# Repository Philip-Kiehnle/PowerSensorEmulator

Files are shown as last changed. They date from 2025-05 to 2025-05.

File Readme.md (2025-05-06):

# Motivation
To measure household electricity consumption in a typical photovoltaic or battery system in Germany, an additional power sensor is installed alongside the grid operator's electricity meter. This additional power sensor can be accessed directly by the Hybrid- or Batteryinverter, because a compatible model is installed by the PV installer or electrician.  
Many models use a Modbus RTU (RS-485) interface with a typical update rate of 1 to 4 Hz.

System overview:

System Overview

This setup has some advantages and disadvantages.  
Disadvantages:
- Device cost of 100–300 € for the extra power sensor
- Installation cost, electrician needed
- Space required in the cabinet
- Power offset between grid operator's electricity meter and extra power sensor, 3–10 Watt
- Power consumption of the device, 0.4–2 Watt
- Minimal voltage/power loss in the main power cable, e.g. due to:
  - Longer cables have to be installed for the measurement setup.
  - A power sensor with an internal current measuring path is installed, as in the [Kaco Hy-switch](https://github.com/Philip-Kiehnle/kaco_blueplanet_hybrid10/tree/main/power_sensor).
  - Clamp current sensors have some loss in their cores.

Advantages:
+ Decent update rate of the power measurement enables fast settling time of the control loop
+ High reliability of the setup because of compatible power meter and inverter
 (Both arguments may be neglected in the future, see section [Impact on system performance](#impact-on-system-performance))

-> Let's take a different approach and use the "already there" optical infrared interface from the grid operator's energy/power meter and develop a protocol conversion adapter that behaves like a compatible power sensor.

# STM32 Microcontroller used as an Emulator for Chint Smart Power Sensor

The first prototype uses an optical read head, a microcontroller, and an RS-485 transceiver.

The optical read head is magnetically attached to the optical interface of the electricity meter. These readers are available online in several versions. Some include a WiFi module such as an ESP32, but for this project the bare UART output model is used. The read head converts the optical UART to an electrical UART signal. The UART signal is connected to the microcontroller, which decodes the Smart Message Language (SML) frames, sent by the electricity meter.  
Three elements are decoded:  

| OBIS code | Description | Variable name in software |
| --- | --- | --- |
| 16.7.0 | Sum active instantaneous power | power |
| 1.8.0 | Positive active energy total | energy_import |
| 2.8.0 | Negative active energy total | energy_export |

The STM32l432kc Nano devboard from ST Microelectronics was used. Its STM32L432KCU3 microcontroller runs at 32 MHz. The microcontroller implements a Modbus slave using the same registers as the original Chint power sensor. An RS-485 transceiver connects the microcontroller and the inverter (Huawei SUN2000-10KTL).

A breadboard was soldered to add connectors and the RS-485 transceiver.  
The prototype requires the following connections:
| Connector | Description |
| --- | --- |
| USB-Power | 5 V supply, e.g. from a 230 V power supply |
| Infrared Read Head | 4 pins for the infrared adapter: VCC, GND, TX, RX.<br>TX can be used in future software version to (re-)enter the meter key in case of a reset during a power outage. The manual [key input procedure](https://youtu.be/aqHauk3bNFA) can be avoided. |
| RS-485 | 2 pins for connection to the inverter |

The prototype uses the following LED states:  
Yellow LED toggles with every decoded SML message of the Smart Meter.  
Green LED toggles on activity on the RS-485 bus.  
Both LEDs toggle fast at 10 Hz when an error handler is called. A microcontroller reboot is triggered automatically after 60 seconds. 

The setup looks like this:

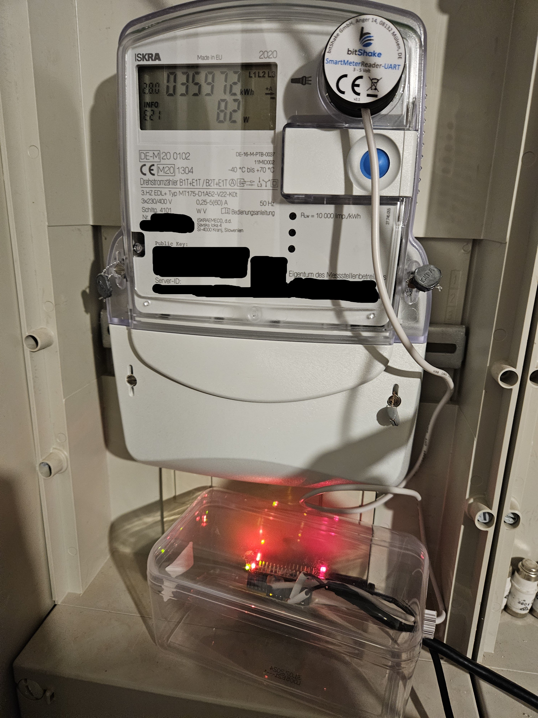
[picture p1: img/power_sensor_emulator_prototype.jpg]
Prototype installation


## Power Consumption
The device is powered from the 230 V grid using an USB power supply.  
The power consumption was measured using the ELV Energy Master power meter:  
5 V 500 mA power supply: 0.4-0.5 W  
Reference test: 5 V 2 A Samsung power supply: 0.4 W

## Cost
STM devboard 18 €  
IR Smart Meter Reader (bitshake UART) 24 €  
RS-485 IC 1 €  
-> 43 €  
-> In a redesigned solution, everything should fit in the infrared reader magnet head.  

## ToDo
Every ~3 month, the prototype needs a power reset, because the Huawei monitoring  shows an error.  
-> Log the communication frames during this situation.

The use of a Huawei battery is untested. If the inverter control loop does not expect the increased delay time of the power measurement, instabilities may occur. In this case, a dead-time compensation (DTC) such as a Smith predictor must be implemented in the power sensor emulator software.

# Chint Smart Power Sensor DTSU666-H

To find the register list of the original Chint Power Sensor, this repo was helpful:
https://github.com/lmatula/ha_chint_pm

## Power Consumption
Single phase connected, all current sensors connected. The power consumption was measured using the ELV Energy Master power meter:  
Display Backlight ON : 0.6 W / 0.6 VA  
Display Backlight OFF: 0.45 W / 0.45 VA

According to datasheet:
Voltage: < 1 W (per phase)  
Current: < 1 VA (per phase) < 20 mA (per phase)

According to Huawei online manual:  
Power consumption of voltage: ≤ 1.5 W / 6 VA  
Power consumption of current: Ib < 10 A : ≤ 0.2 VA   Ib ≥ 10 A :≤ 0.4 VA

### Findings
Data update rate of the Chint Power Sensor?  
-> Registers change with a rate of about 13.6 Hz.

Modbus read interval of the Huawei inverter?  
-> According to Modbus log between 3 and 4 Hz.

Is an exact voltage measurement necessary for the inverter to detect the correct installation of the Chint Power Sensor?  
-> Don't think so, because the original Chint sensor will be detected even if only one phase is connected.

# Data Comparison

Python Modbus register read, with a single phase connected to Chint Power Sensor:

| Key | Chint Power Sensor | STM32 Power Sensor Emulator |
|---|---|---|
| addr | 3 | 3 |
| baud | 11 | 11 |
| clre | 0 | 0 |
| day | 0 | 1 |
| dmpt | 0.0 | 0.0 |
| expep | 0.0 | 0.0 |
| freq | 50.0 | 50.0 |
| hour | 0 | 1 |
| ia | 0.003000000026077032 | 0.0 |
| ib | 0.008999999612569809 | 0.0 |
| ic | 0.00800000037997961 | 0.0 |
| impep | 0.0 | 0.0 |
| irat | 1 | 1 |
| meter_type | 1 | 1 |
| minutes | 17 | 1 |
| month | 0 | 4 |
| net | 0 | 0 |
| pa | 0.10000000149011612 | 0.0 |
| pb | 0.0 | 0.0 |
| pc | 0.0 | 0.0 |
| pfa | 1.0 | 1.0 |
| pfb | 1.0 | 1.0 |
| pfc | 1.0 | 1.0 |
| pft | 1.0 | 1.0 |
| protocol | 3 | 3 |
| pt | 0.10000000149011612 | 0.0 |
| q1eq | 0.0 | 0.0 |
| q2eq | 0.0 | 0.0 |
| q3eq | 0.0 | 0.0 |
| q4eq | 0.0 | 0.0 |
| qa | 0.10000000149011612 | 0.0 |
| qb | 0.0 | 0.0 |
| qc | 0.0 | 0.0 |
| qt | 0.10000000149011612 | 0.0 |
| rev | 109 | 109 |
| secound | 32 | 1 |
| ua | 226.39999389648438 | 230.0 |
| uab | 226.6999969482422 | 400.0 |
| ub | 0.699999988079071 | 230.0 |
| ubc | 0.699999988079071 | 400.0 |
| uc | 0.0 | 230.0 |
| uca | 226.39999389648438 | 400.0 |
| ucode | 701 | 701 |
| urat | 10 | 10 |
| year | 0 | 2024 |

# Ideas

## Power Supply Solutions
The 230 V AC power supply is impractical if there is no socket nearby.

### Inverter USB Port
The Huawei SUN2000-12KTL-M5 has a USB voltage of 5.01V, but the USB port is typically used by the WLAN dongle.  
USB GND is connected to data connector GND (~0,8Ohm).

### Energy Harvester for RS-485 Bus
Use 1.8 V or 3.3 V microcontroller supply voltage. 1.8 V is too low for RS-485 within spec.  
STM32: 84uA/MHz in run mode. On average, 1 MHz should be sufficient:  
$` 84\,\mathrm{\mu A} \cdot 1.8\,\mathrm{V} = 151\,\mathrm{\mu W} `$

Use a push-pull microcontroller pin as a half bridge of a boost converter and boost the available voltage/power during TX of the Huawei inverter to 3.3 V bus.  
As a backup, use 2 x 1.5 V Alkaline batteries or a Li-Ion cell.  
Does Huawei inverter use a 120 Ohm termination resistor?  
In this case, the RS-485 transceiver IC will probably consume too much energy during the transmission of the data registers to the inverter.

Test of available RS-485 bus power of a Huawei SUN2000-12KTL-M5:

RS-485 pins have 2.554 V and 2.084 V to GND.

Connected 470 Ohm from RS-485 pin to GND:  
0.147V -> 0.31mA; 0.046mW  
0.12V -> 0.26mA; 0.03mW  
-> no harvesting seems possible if the transceiver is inactive.  
Or Impedance matching is necessary:  
(2.554V-0.147V)/0.31mA=7.76kOhm  
-> ((2.554V/2)^2)/(7.76k/2)=0.42mW

Energyharvesting during TX of the inverter:  
Duration of bus activity?

# Impact on System Performance
The grid operator's electricity meter may not send the current power via its optical interface per default. A pin code from the grid operator has to be entered via the optical interface with a torch, so the meter sends the actual power every second (1 Hz). The extra meter has a typical update rate of 1 to 4 Hz, but devices with higher update rates are available (e.g. [Kaco Hy-switch](https://github.com/Philip-Kiehnle/kaco_blueplanet_hybrid10/tree/main/power_sensor)).

The ISKRA MT175 and MT631 electricity meters store energy consumption in 0.1 Wh increments. This equals a consumption of 360 Watt for 1 second. A hint for this step size is the printed marking "10000 imp/kWh" on the meter housing.  
For larger load steps, the electricity meter counts the mismatch between battery inverter power and consumption.

Let's compare the system behavior using the grid operator's electricity meter as a power sensor versus a dedicated power sensor.  
Assumptions:
1. Dedicated power sensor and inverter control loop are super-fast and no mismatch due to load steps occurs.
2. Dedicated power sensor has a power consumption of 1 W.
3. Dedicated power sensor has 5 W offset.
4. Power loss in the current sensor cores is neglected.
5. Power sensor emulator has a power consumption of 0.4 W
6. During cooking with a glass ceramic hob at a medium power level, 2 kW load steps occur with a period of 5 sec on 5 sec off. This power level is used for 30 minutes every day. In 50% of the cooking sessions, the PV input is so high that there is no mismatch.
7. The inverter power matches the load 2 sec after the load step occurs.
8. Electricity price is 0.3 € per kWh.
9. Cost of feed-in from battery: 0.15 €. (When mismatch causes feed-in, battery power is fed to grid for feed-in tariff. But must be purchased again, when battery gets empty.)
10. Feed-in tariff: 0.08 €
11. In 50% of the 24/7 self-consumption, PV power feed-in is available.

**Dedicated Power Sensor**  
In one year, the dedicated power sensor self-consumption causes:  
$`8760\,\mathrm{h} \cdot (5\,\mathrm{W} + 1\,\mathrm{W}) = 52.6\,\mathrm{kWh}`$  
grid consumption and no extra feed-in from the battery.

**Power Sensor Emulator (Smart Meter Adapter)**  
In one year, the power sensor emulator causes:  
$`8760\,\mathrm{h} \cdot 0.4\,\mathrm{W} = 3.5\,\mathrm{kWh}`$  
grid consumption.  
Using the grid operator's electricity meter, the system causes mismatch only when the glass ceramic hob is used. The mismatch during a cooking session using the medium power level causes the grid consumption / feed-in scheme:
- **2 sec × 2 kW** grid **consumption**  
- **3 sec × 0 kW** grid **consumption**  
- **2 sec × 2 kW** grid **feed-in**  
- **3 sec × 0 kW** grid **feed-in**

This situation occurs for $`50\% \cdot 30\,\mathrm{min} = 0.25\,\mathrm{h}
`$  
So the energy impact is: $`
\left( \frac{2\,\mathrm{s}}{10\,\mathrm{s}} \cdot 0.25\,\mathrm{h} \right) \cdot 2\,\mathrm{kW} = 0.1\,\mathrm{kWh}`$
grid consumption and the same amount of grid feed-in.  
Annually, this sums up to:  
$`365 \cdot 0.1\,\mathrm{kWh} = 36.5\,\mathrm{kWh}`$

**Economical Perspective**  
<ins>Initial cost:</ins>  
Cost of extra power sensor: 100 € + 150 € installation  
Cost of power sensor emulator: 50 € + self-installation (no electrician needed)

<ins>Runtime cost in 15 years:</ins>  
Dedicated power sensor:  
$` 15\,\mathrm{years} \cdot 52.56\,\mathrm{kWh} \cdot (0.3\,\text{€/kWh} + 0.08\,\text{€/kWh})/2 = 149.8\,€`$  
Power sensor emulator:  
$` \begin{aligned} 15\,\mathrm{years} \cdot & ( 3.5\,\mathrm{kWh} \cdot (0.3\,\text{€/kWh} + 0.08\,\text{€/kWh})/2\\ & + 36.5\,\mathrm{kWh} \cdot (0.3\,\text{€/kWh} + 0.15\,\text{€/kWh})) = 256.35\,€ \end{aligned}`$

<ins>Overall Cost:</ins>  
Dedicated power sensor: 250 € + 149.8 € = **399.8 €**  
Emulator: 50 € + 256.35 € = **306.35 €**

**Outlook**
- A predictive controller can improve the mismatch, by learning the behavior of the glass ceramic hob and the user.
- A custom inverter with direct input of SML data without a protocol translator can improve the loop settling time to e.g. 1.1 sec instead of 2 sec. A GaN-based [PV battery inverter](https://github.com/Philip-Kiehnle/PVBatteryInverter) using this feature is under development.
- The grid operator's electricity meter should not count in tiny 0.1 Wh steps (increments). A step size to compensate a 3.6 kW load within 10 seconds should be suitable. This corresponds to 10 Wh increments.

# Background Story
The project was triggered by a friend with a Huawei SUN2000-10KTL inverter, who wanted to buy a Huawei Luna battery. After some research, I found that the Huawei battery is not a typical high voltage battery. It consists of stackable 48 V battery modules with an internal DCDC converter. However, the module voltage does not add up as usual because the modules are connected in parallel. The top stack contains another DCDC converter, and I had my doubts about its efficiency, especially at low loads, which occur overnight. [Application Note: Energy Efficiency of Smart String Energy Storage
System LUNA2000](https://www.photovoltaikforum.com/core/attachment/426947-application-note-luna2000-efficiency-pdf/)  
In order to check the household's electricity consumption at night, we wanted to log the data. The PV installer sold the power meter for the system some years ago, but did not install it. So the original Chint power sensor can be used for protocol reverse engineering and to develop the protocol adapter.

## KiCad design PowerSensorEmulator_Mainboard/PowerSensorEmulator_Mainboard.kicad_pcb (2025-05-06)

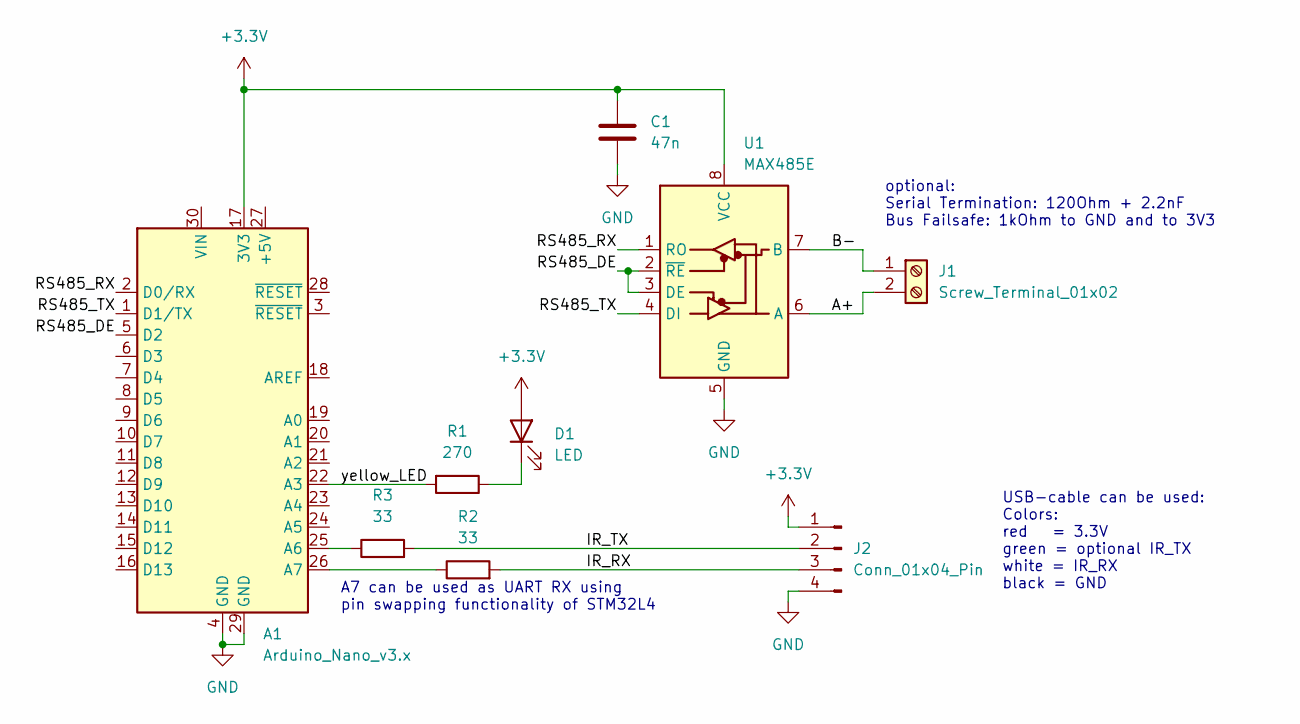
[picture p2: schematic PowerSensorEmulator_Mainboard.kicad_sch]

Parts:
A1: Arduino_Nano_v3.x; Arduino_Nano
C1: 47n; C_Disc_D3.0mm_W1.6mm_P2.50mm
D1: LED; LED_D2.0mm_W4.8mm_H2.5mm_FlatTop
J1: Screw_Terminal_01x02; TerminalBlock_Phoenix_MKDS-1,5-2-5.08_1x02_P5.08mm_Horizont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
J2: Conn_01x04_Pin; PinHeader_1x04_P2.54mm_Vertical
R1: 270; R_0805_2012Metric
R2, R3: 33; R_0805_2012Metric
U1: MAX485E; DIP-8_W7.62mm

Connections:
+3.3V: A1.17 (3V3), C1.1, D1.2 (A), J2.1, U1.8 (VCC)
/A+: J1.2, U1.6 (A)
/B-: J1.1, U1.7 (B)
/IR_RX: J2.3, R2.2
/IR_TX: J2.2, R3.2
/RS485_DE: A1.5 (D2), U1.2 (~RE), U1.3 (DE)
/RS485_RX: A1.2 (D0/RX), U1.1 (RO)
/RS485_TX: A1.1 (D1/TX), U1.4 (DI)
/yellow_LED: A1.22 (A3), R1.2
GND: A1.4 (GND), A1.29 (GND), C1.2, J2.4, U1.5 (GND)
unnamed: A1.25 (A6), R3.1
unnamed: A1.26 (A7), R2.1
unnamed: D1.1 (K), R1.1

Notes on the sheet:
USB-cable can be used: Colors: red = 3.3V green = optional IR_TX white = IR_RX black = GND
A7 can be used as UART RX using pin swapping functionality of STM32L4
optional: Serial Termination: 120Ohm + 2.2nF Bus Failsafe: 1kOhm to GND and to 3V3

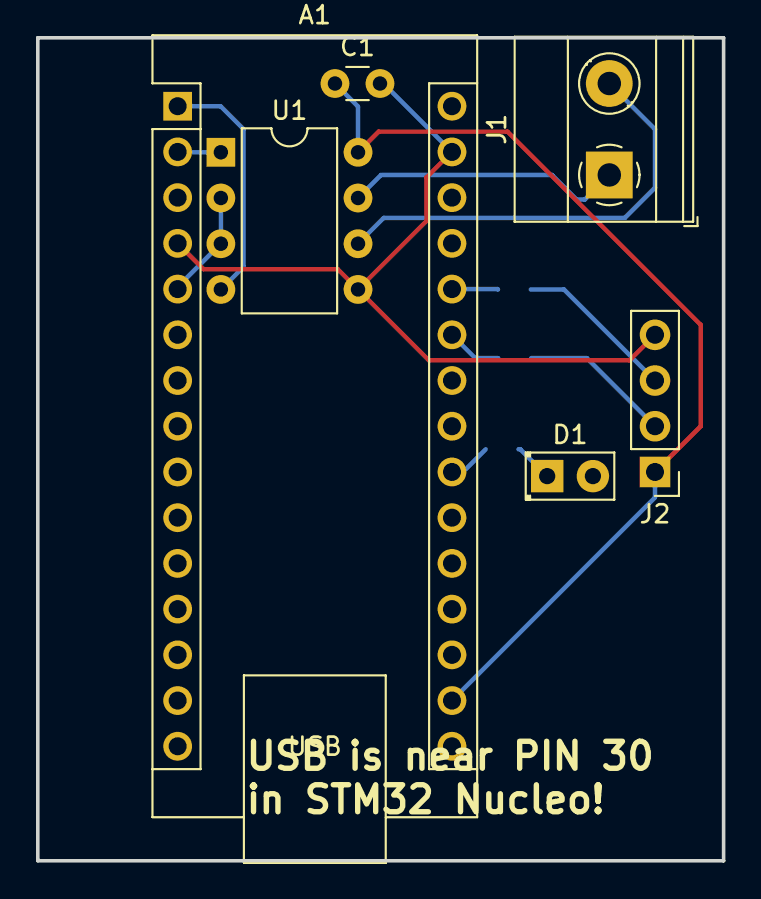
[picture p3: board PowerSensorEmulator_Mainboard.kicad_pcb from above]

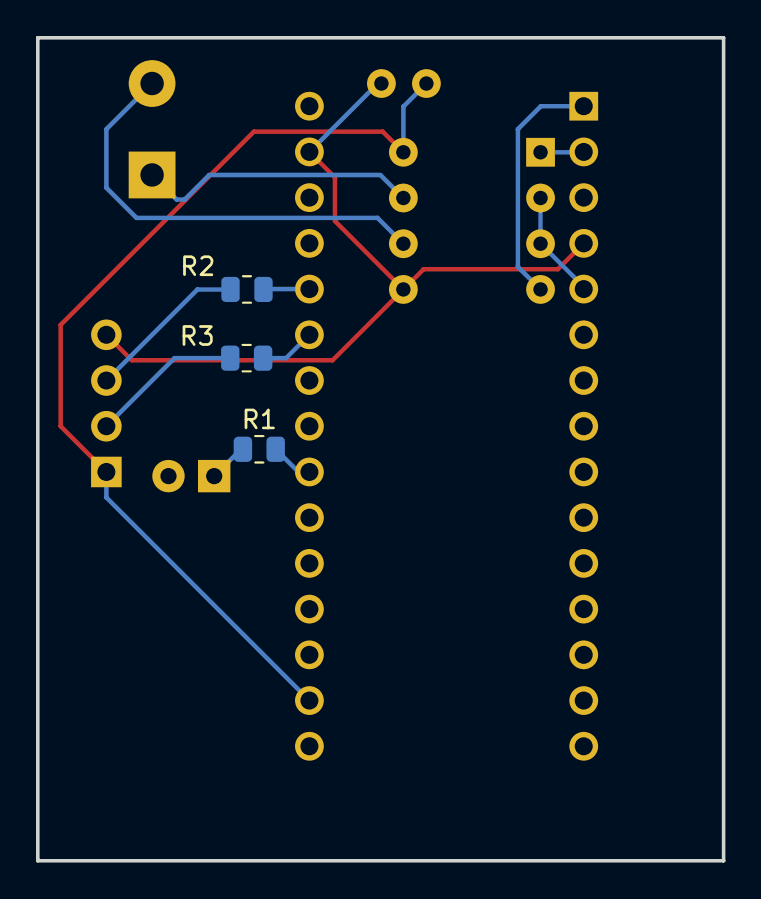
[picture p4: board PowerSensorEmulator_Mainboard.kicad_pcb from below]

Board: 2 copper layers, 38.1 x 45.7 mm, 9 parts (3 on the bottom side), 13 nets.

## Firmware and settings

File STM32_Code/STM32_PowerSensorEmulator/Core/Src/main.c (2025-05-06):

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
/* Includes ------------------------------------------------------------------*/
#include "main.h"

/* USER CODE BEGIN Includes */
#include <stdbool.h>
#include <stdlib.h>
#include <string.h>
//#include <modbus.h>
#include <chintPowerSensor_modbus.h>
#include <sml/sml_parser.h>

/* USER CODE END Includes */

/* USER CODE BEGIN PD */
#define uSend(x) uartSend((char *)x, sizeof x)
/* USER CODE END PD */

IWDG_HandleTypeDef hiwdg;

UART_HandleTypeDef huart1;
UART_HandleTypeDef huart2;
DMA_HandleTypeDef hdma_usart1_rx;
DMA_HandleTypeDef hdma_usart2_rx;

/* USER CODE BEGIN PV */

// UART is used for production and pins are swapped
// -> avoid driving Nucleo UART TX pin and set debug output to 0
// Because of pin swapping, Nucleo UART receives smart meter messages
#define DEBUG_OUTPUT 0
char debug_tx_buf[50];

// **********************
// USART1 is RS485 Modbus
// **********************
#define RS485_RX_BUFFER_SIZE   100
uint8_t rs485_rxDMAbuf[RS485_RX_BUFFER_SIZE] = {0};

volatile bool request_restart_rs485_rx;
volatile bool request_restart_ir_smart_meter_rx;
mbus_t modbus;


// ****************************************
// USART2 is Smart Meter Infrared Interface
// ****************************************
// test in linux:
// stty raw -F /dev/ttyACM0 9600  # without raw, linux adds \r to \n and corrupts data!
// does not work in final version, because tx and rx pin have to be swapped to access rx pin
#define IR_RX_BUFFER_SIZE 1024
uint8_t ir_rxDMAbuf[IR_RX_BUFFER_SIZE] = {0};
uint8_t ir_rxUSERbuf[IR_RX_BUFFER_SIZE] = {0};

volatile bool request_ir_USERbuf_clear = false;
volatile bool sml_parser_started = false;
volatile uint16_t ir_rxUSERbuf_pos = 0;
__IO uint32_t     uwNbReceivedChars;

meter_model_t METER_MODEL = ISKRA_MT175;  // no CRC check; wait for more data -> does not work with MT631
//meter_model_t METER_MODEL = ISKRA_MT631;  //    CRC check; short data

uint16_t MIN_SML_LEN = 200;  // is set to larger value for ISKRA_MT175

#if 0  // init some testvalues, dont use for production to avoid disturbing the PV-inverter
volatile float power_W = 300;
volatile float energy_export_kWh = 4.0;
volatile float energy_import_kWh = 2.0;
#else
volatile float power_W = 0;
volatile float energy_export_kWh = 0;
volatile float energy_import_kWh = 0;
#endif



/* USER CODE END PV */

void SystemClock_Config(void);
static void MX_GPIO_Init(void);
static void MX_DMA_Init(void);
static void MX_USART2_UART_Init(void);
static void MX_USART1_UART_Init(void);
static void MX_IWDG_Init(void);
/* USER CODE BEGIN PFP */


uint32_t mbus_tickcount()
{
	return HAL_GetTick();
}


void resetWatchdog()
{
	// Watchdog runs at 32/8=4kHz -> ~1sec for 4095
    /* Refresh IWDG: reload counter */
    if(HAL_IWDG_Refresh(&hiwdg) != HAL_OK) {
      /* Refresh Error */
      Error_Handler();
    }
}


void show_sys_error()
{
	  static uint16_t err_cnt = 0;
	  static bool green_led_on;
	  if (green_led_on) {
		  GPIOB->BRR = (1<<3);  // disable green LED and pin D13
		  GPIOA->BRR = (1<<4);  // enable yellow LED (PA4=A3)
		  green_led_on = false;
	  } else {
		  GPIOB->BSRR = (1<<3);  // enable green LED and pin D13
		  GPIOA->BSRR = (1<<4);  // disable yellow LED (PA4=A3)
		  green_led_on = true;
	  }
	  // HAL_Delay(100); does not work without IRQ
	  uint32_t i = 0;
	  while (i<800000) { // ~100ms  with -Ofast
		  i++;
		  asm("nop");
	  }
	  err_cnt++;

	  if (err_cnt >= 600) {  // autoreset after ~60 seconds (-Ofast) if no watchdog overflow
		  NVIC_SystemReset();
	  }
}


void uartSend(char* ptr, int len)
{
#if DEBUG_OUTPUT == 1
	HAL_UART_Transmit(&huart2, (uint8_t *)ptr, len, 10);
#endif
}


void uSendInt(int value)
{
#if DEBUG_OUTPUT == 1
	itoa(value, debug_tx_buf, 10);
	int tx_len=strlen(debug_tx_buf);
	HAL_UART_Transmit(&huart2, (uint8_t *)debug_tx_buf, tx_len, 10);
#endif
}


int mbus_send(const mbus_t context, const uint8_t* data, const uint16_t size)
{
	// V1: blocking during send
	HAL_Delay(1);
	if (HAL_UART_Transmit( &huart1, (uint8_t*) data, size, 1000) == HAL_OK) {
		return size;
	}

	// V2: use DMA
//	if (HAL_UART_Transmit_DMA( &huart1, (uint8_t*) data, size) == HAL_OK) {
//		return size;
//	}

	return 0;
}

void Start_RS485_Reception(void);
void Start_SmartMeterIR_Reception(void);

void UserDataTreatment(UART_HandleTypeDef *huart, uint8_t* pData, uint16_t Size);
/* USER CODE END PFP */

/**
  * @brief  The application entry point.
  * @retval int
  */
int main(void)
{

  /* MCU Configuration--------------------------------------------------------*/

  /* Reset of all peripherals, Initializes the Flash interface and the Systick. */
  HAL_Init();

  /* Configure the system clock */
  SystemClock_Config();

  /* Initialize all configured peripherals */
  MX_GPIO_Init();
  MX_DMA_Init();
  MX_USART2_UART_Init();
  MX_USART1_UART_Init();
  MX_IWDG_Init();
  /* USER CODE BEGIN 2 */

  uint8_t tx_buf[STMODBUS_MAX_RESPONSE_SIZE] = {0};

  Modbus_Conf_t mb_config;
  mb_config.send = &mbus_send;
  mb_config.sendbuf = tx_buf;
  mb_config.sendbuf_sz = STMODBUS_MAX_RESPONSE_SIZE;
  modbus = mbus_powersensor_open(&mb_config);

  resetWatchdog();
  uSend("SM_Adapter  ");
  uSend(__DATE__);
  uSend(" ");
  uSend(__TIME__);
  uSend("\n");

  /*## Check if the system has resumed from IWDG reset ####################*/
  if (__HAL_RCC_GET_FLAG(RCC_FLAG_IWDGRST) != 0x00u)
  {
    uSend("Watchdog caused reset!");
    uSend("\n");
    show_sys_error();
  }

  uint32_t ticks_last_sml_success = HAL_GetTick();

  if (METER_MODEL == ISKRA_MT175) {
  	MIN_SML_LEN = 264;
  }

  Start_SmartMeterIR_Reception();

  Start_RS485_Reception();

  /* USER CODE END 2 */

  /* Infinite loop */
  /* USER CODE BEGIN WHILE */


  while (1)
  {
    /* USER CODE END WHILE */

    /* USER CODE BEGIN 3 */

	  resetWatchdog();
#if 0  // V1: polling
		uint8_t rx_byte;

		if (HAL_UART_Receive(&huart1, &rx_byte, 1, 1) == HAL_OK) {
			rx_buf[pos++] = rx_byte;
			if (pos == 8) {
				total_msg++;
				if (total_msg==2){
					asm("nop");
				}
				for (int i = 0; i<8; i++) {
					mbus_poll(modbus, rx_buf[i]);
				}
				pos = 0;
			}
		}

#else	// V2: async
	if(request_restart_rs485_rx) {
		request_restart_rs485_rx = false;

		if (HAL_ERROR == HAL_UARTEx_ReceiveToIdle_DMA(&huart1, rs485_rxDMAbuf, RS485_RX_BUFFER_SIZE)) {
			Error_Handler();
		}
	}
#endif

	// **************************
	// * Parse Smart Meter Data *
	// **************************

	if(request_restart_ir_smart_meter_rx) {
		request_restart_ir_smart_meter_rx = false;

		if (HAL_ERROR == HAL_UARTEx_ReceiveToIdle_DMA(&huart2, ir_rxDMAbuf, IR_RX_BUFFER_SIZE)) {
			Error_Handler();
		}
	}

	if (request_ir_USERbuf_clear == false) {
		if (ir_rxUSERbuf_pos > MIN_SML_LEN) {
			sml_parser_started = true;
			uSendInt(ir_rxUSERbuf_pos);
			meterdata_t meterdata;
			if (parse_sml((char*)ir_rxUSERbuf, ir_rxUSERbuf_pos, METER_MODEL, &meterdata) == SML_PARSE_OKAY) {
				power_W = meterdata.power;
				energy_export_kWh = meterdata.e_export_100mWh/10000.0;
				energy_import_kWh = meterdata.e_import_100mWh/10000.0;

				ticks_last_sml_success = HAL_GetTick();
				resetWatchdog();
				uSend("SML_OK\n");

				static bool yellow_led_on;
				if (yellow_led_on) {
					GPIOA->BSRR = (1<<4);  // disable yellow LED (PA4=A3)
					yellow_led_on = false;
				} else {
					GPIOA->BRR = (1<<4);  // enable yellow LED (PA4=A3)
					yellow_led_on = true;
				}

			} else {
				uSend("SML_ERR\n");
			}
			sml_parser_started = false;
			request_ir_USERbuf_clear = true;
		}
	}

	// set power to zero in case of broken link to smart meter
	const uint32_t TIMEOUT_SML_SEC = 10;
	const uint32_t TIMEOUT_SML_REBOOT_SEC = 30;
	uint32_t ticks = HAL_GetTick();
	static uint32_t ticks_prev_check;

	if ( ticks > ticks_last_sml_success+TIMEOUT_SML_SEC*1000) {
		if (ticks < ticks_prev_check) {  // prevent error during overflow
			ticks_last_sml_success = 0;  // set to 0 when ticks overflow
		} else {
			power_W = 0;
			if ( ticks > ticks_last_sml_success+TIMEOUT_SML_REBOOT_SEC*1000) {
				NVIC_SystemReset();
			}
		}
	}
	ticks_prev_check = ticks;

  }
  /* USER CODE END 3 */
}

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
/* USER CODE BEGIN 4 */

void Start_SmartMeterIR_Reception(void)
{
  /* Initializes Buffer swap mechanism (used in User callback) :
     - 2 physical buffers aRXBufferA and aRXBufferB (RX_BUFFER_SIZE length)
  */
//  pBufferReadyForReception = aRXBufferA;
//  pBufferReadyForUser      = aRXBufferB;
  uwNbReceivedChars        = 0;

  /* Print user info on PC com port */
  //PrintInfo(&hlpuart1, aTextInfoStart, COUNTOF(aTextInfoStart));

  /* Initializes Rx sequence using Reception To Idle event API.
     As DMA channel associated to UART Rx is configured as Circular,
     reception is endless.
     If reception has to be stopped, call to HAL_UART_AbortReceive() could be used.

     Use of HAL_UARTEx_ReceiveToIdle_DMA service, will generate calls to
     user defined HAL_UARTEx_RxEventCallback callback for each occurrence of
     following events :
     - DMA RX Half Transfer event (HT)
     - DMA RX Transfer Complete event (TC)
     - IDLE event on UART Rx line (indicating a pause is UART reception flow)
  */
  if (HAL_OK != HAL_UARTEx_ReceiveToIdle_DMA(&huart2, ir_rxDMAbuf, IR_RX_BUFFER_SIZE))
  {
    Error_Handler();
  }
}


void Start_RS485_Reception(void)
{
  /* Initializes Rx sequence using Reception To Idle event API.
     As DMA channel associated to UART Rx is configured as Circular,
     reception is endless.
     If reception has to be stopped, call to HAL_UART_AbortReceive() could be used.

     Use of HAL_UARTEx_ReceiveToIdle_DMA service, will generate calls to
     user defined HAL_UARTEx_RxEventCallback callback for each occurrence of
     following events :
     - DMA RX Half Transfer event (HT)
     - DMA RX Transfer Complete event (TC)
     - IDLE event on UART Rx line (indicating a pause is UART reception flow)
  */
  if (HAL_OK != HAL_UARTEx_ReceiveToIdle_DMA(&huart1, rs485_rxDMAbuf, RS485_RX_BUFFER_SIZE))
  {
    Error_Handler();
  }
}


/**
  * @brief  User implementation of the Reception Event Callback
  *         (Rx event notification called after use of advanced reception service).
  * @param  huart UART handle
  * @param  Size  Number of data available in application reception buffer (indicates a position in
  *               reception buffer until which, data are available)
  * @retval None
  */
void HAL_UARTEx_RxEventCallback(UART_HandleTypeDef *huart, uint16_t Size)
{
	if (huart == &huart1) {  // RS485

		static bool green_led_on;
		if (green_led_on) {
			GPIOB->BRR = (1<<3);  // disable green LED and pin D13
			green_led_on = false;
		} else {
			GPIOB->BSRR = (1<<3);  // enable green LED and pin D13
			green_led_on = true;
		}

		for (uint16_t i = 0; i < Size; i++) {
			//pBufferReadyForUser[i] = rs485_rxDMAbuf[i];
			//HAL_UART_Transmit(&huart2, &pBufferReadyForUser[old_pos+i],1, 10);  // debug
			mbus_poll(modbus, rs485_rxDMAbuf[i]);
		}

		request_restart_rs485_rx = true;

	} else {  // Smart Meter Infrared / UART Interface

		static uint32_t ticks_last_rx_ms;
		static uint16_t old_dmabuf_pos = 0;

		if (request_ir_USERbuf_clear) {
			ir_rxUSERbuf_pos = 0;
			request_ir_USERbuf_clear = false;
		}

		if (    sml_parser_started == false   // only write to userbuf if parser is not active
			&& (Size != old_dmabuf_pos)  // check if number of received data in reception buffer has changed
			) {

			if (HAL_GetTick()-ticks_last_rx_ms > 400) { // drop old data after 400ms
				ticks_last_rx_ms = HAL_GetTick();
				ir_rxUSERbuf_pos = 0;
			}

			/* Check if position of index in reception buffer has simply be increased
			   of if end of buffer has been reached */
			if (Size > old_dmabuf_pos) {
				/* Current position is higher than previous one */
				uwNbReceivedChars = Size - old_dmabuf_pos;
				/* Copy received data in "User" buffer for evacuation */
				for (uint16_t i = 0; i < uwNbReceivedChars; i++) {
					ir_rxUSERbuf[ir_rxUSERbuf_pos+i] = ir_rxDMAbuf[old_dmabuf_pos + i];
				}

			} else {
				/* Current position is lower than previous one : end of buffer has been reached */
				/* First copy data from current position till end of buffer */
				uwNbReceivedChars = IR_RX_BUFFER_SIZE - old_dmabuf_pos;
				/* Copy received data in "User" buffer for evacuation */
				for (uint16_t i = 0; i < uwNbReceivedChars; i++)	{
					ir_rxUSERbuf[ir_rxUSERbuf_pos+i] = ir_rxDMAbuf[old_dmabuf_pos + i];
				}
				/* Check and continue with beginning of buffer */
				if (Size > 0) {
					for (uint16_t i = 0; i < Size; i++)	{
						ir_rxUSERbuf[ir_rxUSERbuf_pos+uwNbReceivedChars + i] = ir_rxDMAbuf[i];
					}
					uwNbReceivedChars += Size;
				}
			}

			/* Process received data that has been extracted from Rx User buffer */
			ir_rxUSERbuf_pos += uwNbReceivedChars;

			request_restart_ir_smart_meter_rx = true;
		}

		old_dmabuf_pos = Size;
	}
}
/* USER CODE END 4 */
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


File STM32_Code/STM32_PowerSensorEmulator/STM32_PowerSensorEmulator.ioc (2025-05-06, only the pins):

Mcu.UserName=STM32L432KCUx
PA0.GPIO_Label=MCO [High speed clock in]
PA0.Signal=RCC_CK_IN
PA10.Signal=USART1_RX
PA12.Signal=USART1_DE
PA2.GPIO_Label=VCP_RX_SWAP
PA2.Signal=USART2_TX
PA4.GPIO_Label=YL_LED
PA4.Signal=GPIO_Output
PA7.GPIO_Label=IR_TX
PA7.Signal=GPIO_Output
PA9.Signal=USART1_TX

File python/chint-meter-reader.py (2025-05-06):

#!/usr/bin/python3
import sys
import json
import time
import matplotlib.pyplot as plt
from pymodbus.client import ModbusSerialClient
from pymodbus.payload import BinaryPayloadDecoder
from pymodbus.constants import Endian

#from . import *
from chintPM.chintPM import *
from chintPM.const import *

UART_PORT = '/dev/ttyUSB0'
MODBUS_ID = DEFAULT_SERIAL_SLAVE_ID


data = {CONF_HOST       : None,
        CONF_PORT       : UART_PORT,
        CONF_SLAVE_IDS  : [MODBUS_ID],
        CONF_METER_TYPE : MeterTypes.METER_TYPE_H_3P}
print(data)

entry = ConfigEntry(data=data)
    

#modbus_register_list
# Input Registers (1x16bit R/W)
#0000H REV. version
#0001H UCode Programming password
#0002H ClrE Electric energy zero
#0003H net Selecting of the connection mode net(0:3P4W,13P3W)
#
# Input Registers (1x16bit R)
#000BH Meter type
#
# Input Registers (2x16bit R)
#0x2006 Ua Phase-phase voltage, the unit is V(It is invalid for 3 phase 3 wire)
#0x2008 Ub
#0x200A Uc
#0x2012 Pt Conjunction active power，the unit is W
#0x2014 Pa A phase active power，theunit is W
#0x2016 Pb B phase active power，the unit is W (invalid when three phase three wire)
#0x2018 Pc C phase active power，the unit is W

def _resolve_ph_mode(net: int) -> str:
    if net == 0:
        return PHMODE_3P4W
    else:
        return PHMODE_3P3W
    

def main():
    #######################################
    # Option A: Huawei inverter emualtion #
    #######################################
    if 1:
        if 1: ## Huawei inverter sends meter init bytes during boot
            import serial
            ser = serial.Serial(UART_PORT, 9600, timeout=0.1)
            for i in range(5):
                ser.write(b'\x01\x03\x00\x0B\x00\x01\xF5\xC8')
                #time.sleep(0.001)
                bs = ser.readline()
                if len(bs) > 0:
                    print('Power meter should not repond to init message, but responded:', bs)
                    sys.exit()
            ser.close()
            print('Finished Huawei init...')
        
        print('Create ModbusSerialClient...')
        client = ModbusSerialClient( port=UART_PORT, baudrate=9600, bytesize=8, stopbits=1, parity="N")
        print('connect...')
        client.connect()
        ts_start = time.time()
        pt_last = 0
        ts_rel_last_change = 0
        update_freq_max = 0
        runs = 0

        while 0:  ## fast loop test

            rr = client.read_holding_registers(
                address=2126, count=2, slave=MODBUS_ID
            )
            decoder = BinaryPayloadDecoder.fromRegisters(rr.registers, byteorder=Endian.BIG)
            pt = decoder.decode_32bit_float()

            ts_rel = time.time()-ts_start
            p_str = "ts:{:.3f}".format(ts_rel) + "Pt" + str(pt)
            if (pt != pt_last) :
                interval = ts_rel-ts_rel_last_change
                update_freq = 1/interval
                ts_rel_last_change = ts_rel
                if (runs > 0):
                #if (runs > 0 and runs > 50):  # does not make a difference
                    update_freq_max = max(update_freq, update_freq_max)
                    p_str += " change_interval={:.3f} freq={:.3f} freq_max={:.3f}".format(interval, update_freq, update_freq_max)
            pt_last = pt
            runs += 1
            #if (runs > 50):  # does not make a difference
            print(p_str)

        if 0:

            print("read_holding_registers...")
            rr = client.read_holding_registers(0X401E, 4, slave=MODBUS_ID)
            if rr.isError():
                print(f"Received Modbus library error({rr})")
            else:
                print('0X4026\n',rr.registers)
                decoder = BinaryPayloadDecoder.fromRegisters(
                        rr.registers, byteorder=Endian.BIG
                )
                impep = decoder.decode_32bit_float()
                print('energy import', impep)

            rr = client.read_holding_registers(
                address=0x0, count=4, slave=MODBUS_ID
            )

            if rr.isError():
                print(f"Received Modbus library error({rr})")
            else:
                print("done")

            decoder = BinaryPayloadDecoder.fromRegisters(rr.registers, byteorder=Endian.BIG)
            rev = decoder.decode_16bit_uint()
            ucode = decoder.decode_16bit_uint()
            clre = decoder.decode_16bit_uint()
            net = decoder.decode_16bit_uint()
            print('rev', rev)
            print('ucode', ucode)
            print('clre', clre)
            print('net', net)

            # read device_type
            rr = client.read_holding_registers(
                address=0xB, count=1, slave=MODBUS_ID
            )
            decoder = BinaryPayloadDecoder.fromRegisters(rr.registers, byteorder=Endian.BIG)
            device_type = decoder.decode_16bit_uint()

            print("Successfully connected to pm phase mode %s", net)

            #meter_type_name = "DTSU-666"
            meter_type_name = "DTSU-666-H"

            result = {
                "model_name": f"{meter_type_name} ({UART_PORT}@{MODBUS_ID})",
                "rev": rev,
                CONF_PHASE_MODE: _resolve_ph_mode(net),
            }

            print(result)

            rr = client.read_input_registers(0X2006, 3, slave=MODBUS_ID)

            if rr.isError():
                print(f"Received Modbus library error({rr})")
            else:
                print('Ua 0X2006\n',rr.registers)
                print(rr.registers[0], rr.registers[1])

                decoder = BinaryPayloadDecoder.fromRegisters(
                        rr.registers, byteorder=Endian.BIG
                )

                # Uab Line -line voltage, the unit is V
                uab = decoder.decode_32bit_float()
                print('uab', uab)

            rr = client.read_input_registers(0X2014, 3, slave=MODBUS_ID)

            if rr.isError():
                print(f"Received Modbus library error({rr})")
            else:
                print('Pa 0X2014\n',rr.registers)
                print(rr.registers[0], rr.registers[1])


        print('Read register of Huawei specific -H version\n')
        rr = client.read_holding_registers(
            address=2001, count=1, slave=MODBUS_ID
        )
        decoder = BinaryPayloadDecoder.fromRegisters(rr.registers, byteorder=Endian.BIG)
        magic_key = decoder.decode_16bit_uint()
        print('magic_key', magic_key)
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

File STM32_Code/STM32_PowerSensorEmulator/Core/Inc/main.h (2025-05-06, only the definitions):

#define MCO_Pin GPIO_PIN_0
#define MCO_GPIO_Port GPIOA
#define VCP_RX_SWAP_Pin GPIO_PIN_2
#define VCP_RX_SWAP_GPIO_Port GPIOA
#define YL_LED_Pin GPIO_PIN_4
#define YL_LED_GPIO_Port GPIOA
#define IR_TX_Pin GPIO_PIN_7
#define IR_TX_GPIO_Port GPIOA
#define SWDIO_Pin GPIO_PIN_13
#define SWDIO_GPIO_Port GPIOA
#define SWCLK_Pin GPIO_PIN_14
#define SWCLK_GPIO_Port GPIOA
#define VCP_TX_SWAP_Pin GPIO_PIN_15
#define VCP_TX_SWAP_GPIO_Port GPIOA
#define LD3_Pin GPIO_PIN_3
#define LD3_GPIO_Port GPIOB

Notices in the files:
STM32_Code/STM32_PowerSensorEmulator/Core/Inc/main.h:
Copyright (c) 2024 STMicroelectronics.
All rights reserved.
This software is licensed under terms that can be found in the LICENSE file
